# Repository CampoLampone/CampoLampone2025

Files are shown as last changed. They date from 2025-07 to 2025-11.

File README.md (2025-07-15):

# CampoLampone2025
This is repo for Firmware, PCBs, Images, schemes and stuff

## Setup

1) Clone with all the submodules
```
	git clone <repository-name-ssh-or-https> --recursive
```

2) Add TinyUSB to SDK
```
	cd pico-sdk && git submodule update --init
```

3) Create build dir and build da project!
```
	mkdir build && cd build
	cmake ..
	make -j<number of jobs>
```

## TODO

- [ ] Check when to move from pico-sdk develop branch to main branch

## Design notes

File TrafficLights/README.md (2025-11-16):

# Traffic lights
The traffic lights of Campo Lampone's city can be controlled by any Wifi capable MCU, in the case of Campo Lampone 2025 it was ESP32-S3 with MicroPython.
All of them depend on a central server with the schedule in it, they also sync to NTP.

Every controller has it's own `CONTROLLER_NAME` under which it tries to download it's config on start.

## Server
The shedule is kept in a JSON file by the [main server](server/main.py). The server is written in Python using FastAPI.
It has a relatively friendly frontend made in React with Vite coded with the help of an LLM. Its code is [here](campo/).

Both of them can be conveniently started at the same time in Docker using:
```bash
docker compose up -d
```
That opens the backend on port `8000` and an Nginx server serving a statically built version of the frontend on the port `8080`.

## Controllers
After installing MicroPython on your Wifi capable MCU of choice, you can install `main.py` on the device using MicroPython's `mpremote` utility.
Before copying the code on the device, you should replace these placeholders in the code:
- `WIFI_SSID`
- `WIFI_PASSWORD`
- `BACKEND_URL`
- `CONTROLLER_NAME`

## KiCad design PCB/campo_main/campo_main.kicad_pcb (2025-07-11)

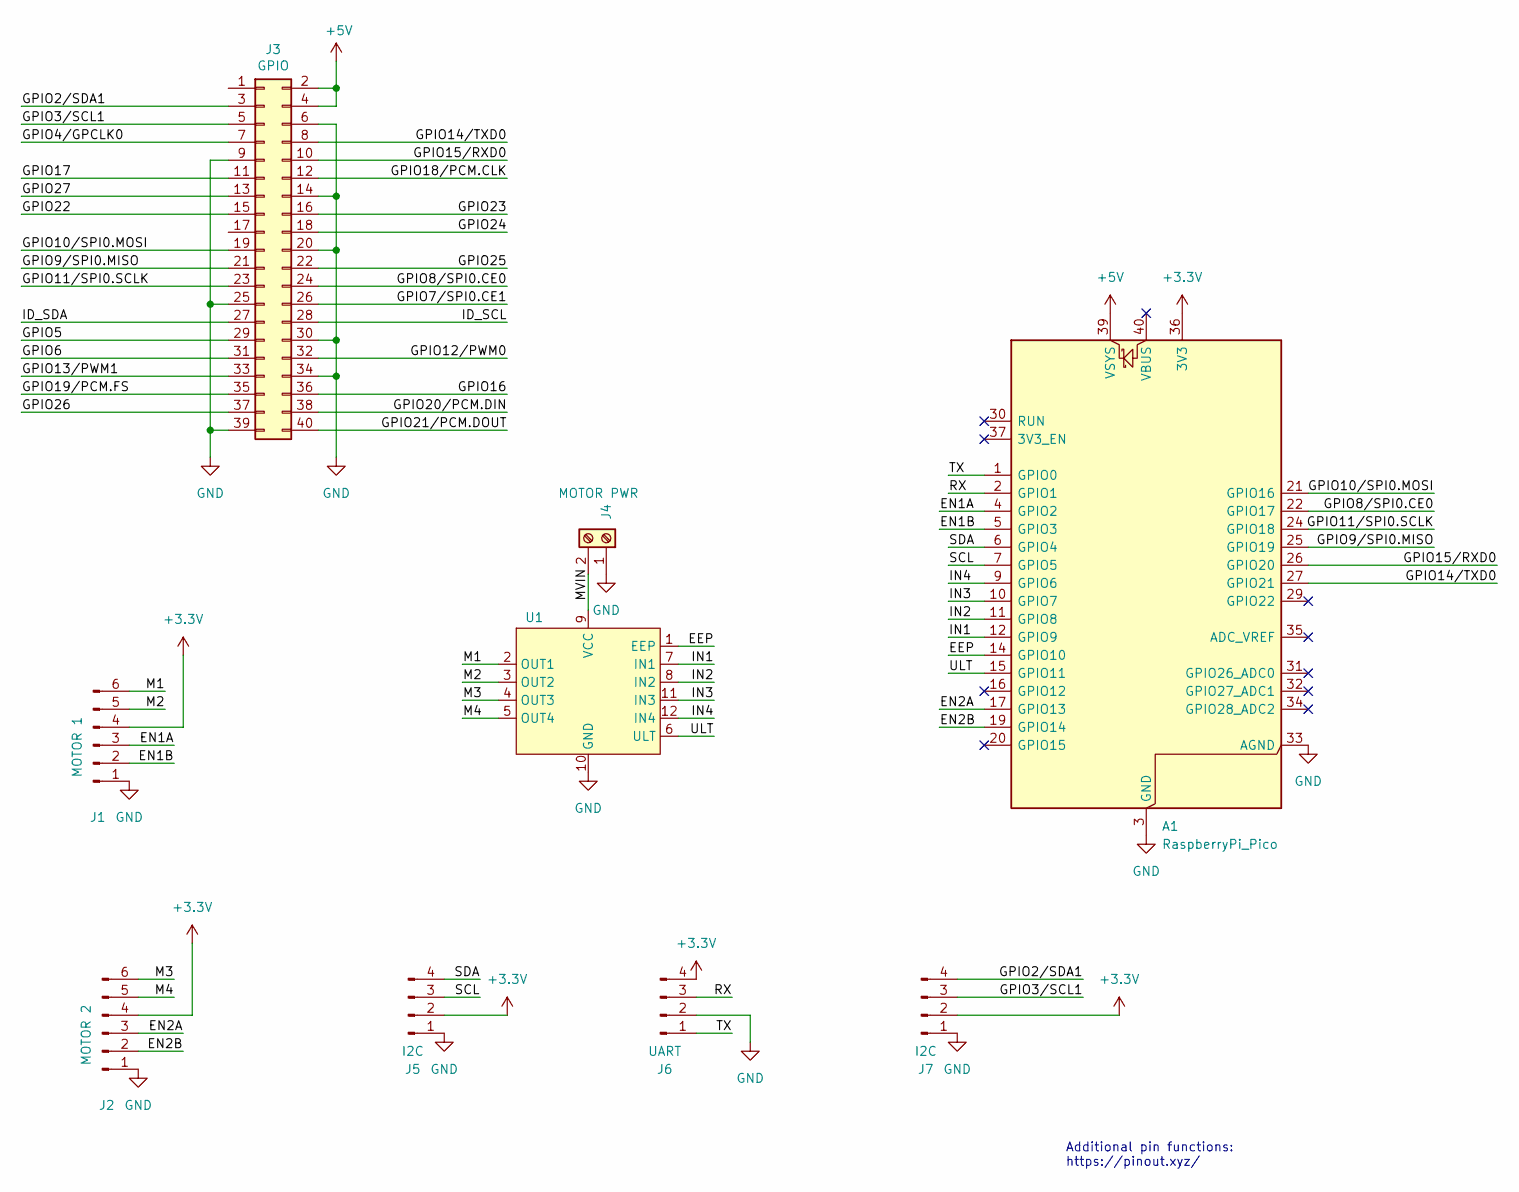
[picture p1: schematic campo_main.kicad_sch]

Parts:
A1: RaspberryPi_Pico; RaspberryPi_Pico_Common_Unspecified
J1: MOTOR 1; PinHeader_1x06_P2.54mm_Vertical
J2: MOTOR 2; PinHeader_1x06_P2.54mm_Vertical
J3: GPIO; PinSocket_2x20_P2.54mm_Vertical
J4: MOTOR PWR; TerminalBlock_4Ucon_1x02_P3.50mm_Horizontal
J5, J7: I2C; PinHeader_1x04_P2.54mm_Vertical
J6: UART; PinHeader_1x04_P2.54mm_Vertical
U1: DRV8833

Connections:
+3.3V: A1.36 (3V3), J1.4, J2.4, J5.2, J6.4, J7.2
+5V: A1.39 (VSYS), J3.2, J3.4
/EEP: A1.14 (GPIO10), U1.1 (EEP)
/EN1A: A1.4 (GPIO2), J1.3
/EN1B: A1.5 (GPIO3), J1.2
/EN2A: A1.17 (GPIO13), J2.3
/EN2B: A1.19 (GPIO14), J2.2
/GPIO2/SDA1: J3.3, J7.4
/GPIO3/SCL1: J3.5, J7.3
/GPIO4/GPCLK0: J3.7
/GPIO5: J3.29
/GPIO6: J3.31
/GPIO7/SPI0.CE1: J3.26
/GPIO8/SPI0.CE0: A1.22 (GPIO17), J3.24
/GPIO9/SPI0.MISO: A1.25 (GPIO19), J3.21
/GPIO10/SPI0.MOSI: A1.21 (GPIO16), J3.19
/GPIO11/SPI0.SCLK: A1.24 (GPIO18), J3.23
/GPIO12/PWM0: J3.32
/GPIO13/PWM1: J3.33
/GPIO14/TXD0: A1.27 (GPIO21), J3.8
/GPIO15/RXD0: A1.26 (GPIO20), J3.10
/GPIO16: J3.36
/GPIO17: J3.11
/GPIO18/PCM.CLK: J3.12
/GPIO19/PCM.FS: J3.35
/GPIO20/PCM.DIN: J3.38
/GPIO21/PCM.DOUT: J3.40
/GPIO22: J3.15
/GPIO23: J3.16
/GPIO24: J3.18
/GPIO25: J3.22
/GPIO26: J3.37
/GPIO27: J3.13
/ID_SCL: J3.28
/ID_SDA: J3.27
/IN1: A1.12 (GPIO9), U1.7 (IN1)
/IN2: A1.11 (GPIO8), U1.8 (IN2)
/IN3: A1.10 (GPIO7), U1.11 (IN3)
/IN4: A1.9 (GPIO6), U1.12 (IN4)
/M1: J1.6, U1.2 (OUT1)
/M2: J1.5, U1.3 (OUT2)
/M3: J2.6, U1.4 (OUT3)
/M4: J2.5, U1.5 (OUT4)
/MVIN: J4.2, U1.9 (VCC)
/RX: A1.2 (GPIO1), J6.3
/SCL: A1.7 (GPIO5), J5.3
/SDA: A1.6 (GPIO4), J5.4
/TX: A1.1 (GPIO0), J6.1
/ULT: A1.15 (GPIO11), U1.6 (ULT)
GND: A1.3 (GND), A1.8 (GND), A1.13 (GND), A1.18 (GND), A1.23 (GND), A1.28 (GND), A1.33 (AGND), A1.38 (GND), J1.1, J2.1, J3.6, J3.9, J3.14, J3.20, J3.25, J3.30, J3.34, J3.39, J4.1, J5.1, J6.2, J7.1, U1.10 (GND)

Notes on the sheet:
Additional pin functions: https://pinout.xyz/

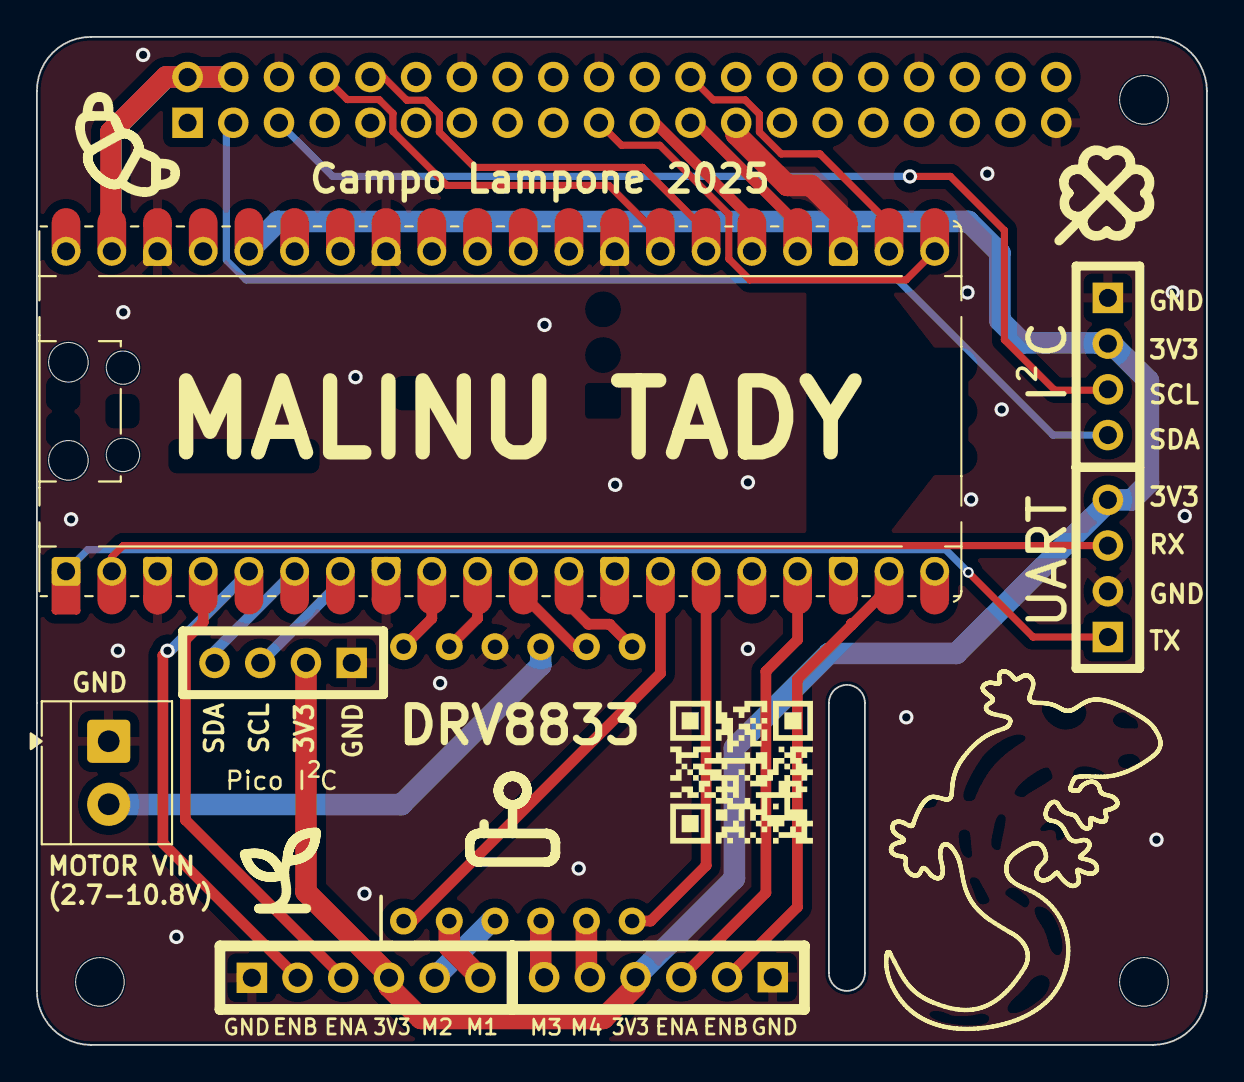
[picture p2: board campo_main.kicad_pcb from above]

Board: 2 copper layers, 65.0 x 56.0 mm, 12 parts (1 on the bottom side), 30 nets.

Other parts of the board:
MH2, MH3, MH4: MountingHole_2.7mm_M2.5

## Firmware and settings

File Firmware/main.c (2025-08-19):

#include "speed_controller.h"
#include <stdint.h>
#include <stdio.h>
#include "pico/stdio_usb.h"
#include <pico/time.h>
#include <string.h>
#include "hardware/i2c.h"
#include "motor.h"
#include "encoder.h"
#include "display.h"
#include "config.h"
#include "spi.h"
#include "spi_cmds.h"

#if TEST_MODE > 0
#include "tests.h"
#endif

enum command {
    COMMAND_SPEED,
    COMMAND_POSITION,
    COMMAND_BRAKE,
    COMMAND_STOP,
    COMMAND_COAST
};

int16_t speed_target[MOTOR_COUNT] = {0, 0};
int8_t position_target[MOTOR_COUNT] = {0, 0};
uint8_t current_cmd = COMMAND_COAST;
substep_state_t encoders_states[ENCODER_COUNT];
display_data_t display_struct;

void spi_callback(uint8_t *data){
    switch (data[0]) {
        case SPI_CMD_SET_SPEED_BASE:
            current_cmd = COMMAND_SPEED;
            speed_target[0] = (data[1] << 8) | data[2];
            break;
        case SPI_CMD_SET_SPEED_BASE + SPI_CMD_NEXT_MOTOR:
            current_cmd = COMMAND_SPEED;
            speed_target[1] = (data[1] << 8) | data[2];
            break;
        case SPI_CMD_SET_POSITION_BASE:
            current_cmd = COMMAND_POSITION;
            position_target[0] = data[1];
            speed_target[0] = (data[2] << 8) | data[3];
            break;
        case SPI_CMD_SET_POSITION_BASE + SPI_CMD_NEXT_MOTOR:
            current_cmd = COMMAND_POSITION;
            position_target[1] = data[1];
            speed_target[1] = (data[2] << 8) | data[3];
            break;
        case SPI_CMD_COAST:
            current_cmd = COMMAND_COAST;
            break;
        case SPI_CMD_BRAKE:
            current_cmd = COMMAND_BRAKE;
            break;
        case SPI_CMD_REL_ESTOP:
            reset_emergency_stop();
            clear_pid_cache();
            break;
        case SPI_CMD_SET_HOSTNAME:
            strcpy(display_struct.ip, (char*)&data[1]);
            break;
    }
}


int main() {
    stdio_usb_init();
    sleep_ms(2000);
    printf("Program Started\n");
#if TEST_MODE == 0
    motor_init();
    encoders_init();
    spi_init(spi_callback);
    speed_controller_init(PID_KP, PID_KI, PID_KD);
    reset_emergency_stop();
    i2c_init(i2c_default, 400 * 1000);
    ssd1306_gpio_init(PICO_DEFAULT_I2C_SDA_PIN, PICO_DEFAULT_I2C_SCL_PIN);

    ssd1306_t disp;
    disp.external_vcc=false;

    // Check if the device is present

    int ret = i2c_read_timeout_us(i2c_default, 0x3C, NULL, 1, false, 10000);

    if (ret >= 0) {
        printf("I2C device found at address 0x%02X\n", 0x3C);
        ssd1306_init(&disp, 128, 64, true, 0x3C, i2c_default);
        ssd1306_clear(&disp);
    } else {
        printf("No I2C device found at address 0x%02X. Is the display connected correctly?\n", 0x3C);
    }

    absolute_time_t last_time = get_absolute_time();
    int wrum_time = last_time;
    while (true) {
        absolute_time_t current_time = get_absolute_time();
        int64_t delta_us = absolute_time_diff_us(last_time, current_time);
        last_time = current_time;

        compute_encoders_rpm(delta_us / 1000.0);
        switch (current_cmd) {
            case (COMMAND_SPEED):
                control_speed(speed_target, delta_us / 1000.0);
                break;
            case (COMMAND_POSITION):
                // TODO: Implement position control
                // control_position(position_target, speed_target, delta_us / 1000.0);
                break;
            case (COMMAND_COAST):
                for (int motor = 0; motor < MOTOR_COUNT; motor++) {
                    motor_coast(motor);
                }
                break;
            case (COMMAND_BRAKE):
                for (int motor = 0; motor < MOTOR_COUNT; motor++) {
                    motor_brake(motor);
                }
                break;
        }

        if (ret >= 0) {
            snprintf(display_struct.msg, DISP_BUF(MSG_SCALE), get_emergency_stop() ? "ESTOP" : "     ");
            snprintf(display_struct.stuff, DISP_BUF(STUFF_SCALE), "%4.0f  %4.0f", get_rpm(MOTOR_LEFT), get_rpm(MOTOR_RIGHT));
            ssd1306_draw_struct(&disp, &display_struct);
            ssd1306_show(&disp);
        }

        sleep_ms(10); // loop delay for PID
    }
#elif TEST_MODE > 0
    do_tests();
#endif

}

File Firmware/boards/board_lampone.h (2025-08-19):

/*
 * Copyright (c) 2020 Raspberry Pi (Trading) Ltd.
 *
 * Edited to suit LampOne's board - Plajta 2025 - Salivon Andrii
 *
 * SPDX-License-Identifier: BSD-3-Clause
 */

// -----------------------------------------------------
// NOTE: THIS HEADER IS ALSO INCLUDED BY ASSEMBLER SO
//       SHOULD ONLY CONSIST OF PREPROCESSOR DIRECTIVES
// -----------------------------------------------------

#ifndef _BOARDS_LAMPONE_H
#define _BOARDS_LAMPONE_H

// For board detection
#define LAMPONE

//---------------------------//
//   BOARD PIN DEFINITIONS   //
//---------------------------//
#include "boards/pico.h" // IWYU pragma: keep

// --- MOTOR PINS ---
#define BOARD_MOTOR_EEP 10
#define BOARD_MOTOR_PIN_1 9 // LEFT
#define BOARD_MOTOR_PIN_2 8
#define BOARD_MOTOR_PIN_3 7 // RIGHT
#define BOARD_MOTOR_PIN_4 6

// --- ENCODER PINS ---
#define BOARD_ENCODER1_PIN_A 2 // LEFT
#define BOARD_ENCODER1_PIN_B 3
#define BOARD_ENCODER2_PIN_A 13 // RIGHT
#define BOARD_ENCODER2_PIN_B 14

#endif //_BOARDS_LAMPONE_H

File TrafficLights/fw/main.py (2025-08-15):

# "defines" - always check before deploy
WIFI_SSID = "<YOUR SSID>"
WIFI_PASSWORD = "<YOUR PASSWD>"

BACKEND_URL = "http://192.168.1.156:8000"

CONTROLLER_NAME = "controller1"
NUM_LIGHTS = 2

# setup network
import machine
import network

wlan = network.WLAN()
wlan.active(True)
if not wlan.isconnected():
    print('connecting to network...')
    wlan.connect(WIFI_SSID, WIFI_PASSWORD)
    while not wlan.isconnected():
        machine.idle()
print('network config:', wlan.ipconfig('addr4'))

# sync time
from machine import RTC
import ntptime

rtc = RTC()
ntptime.settime()
print("Datetime: " + str(rtc.datetime()))

# get JSON
import requests
import json

url = BACKEND_URL + "/controllers/" + CONTROLLER_NAME

data = None

try:
    r = requests.get(url)
    if r.status_code == 200:
        data = json.loads(r.text)
        print("Received JSON:", data)
    else:
        print("HTTP Error:", r.status_code)
    r.close()  # important to free memory
except Exception as e:
    print("Request failed:", e)

# setup traffic lights

from machine import Pin, Timer
import time

class Light:
    def __init__(self, red, yellow, green):
        self.red = red
        self.yellow = yellow
        self.green = green
        self.last_outage = False

    def tick_outage(self):
        if not self.last_outage:
            self.last_outage = True
            self.red.off()
            self.yellow.on()
            self.green.off()
        else:
            self.yellow.toggle()

    def set_phase(self, phase):
        self.last_outage = False
        phase_states = {
            "red":       (1, 0, 0),
            "redyellow": (1, 1, 0),
            "yellow":    (0, 1, 0),
            "green":     (0, 0, 1),
            "off":       (0, 0, 0),
        }

        # Get the current state, default to all off if unknown
        r_state, y_state, g_state = phase_states.get(phase, (0, 0, 0))

        self.red.on() if r_state else self.red.off()
        self.yellow.on() if y_state else self.yellow.off()
        self.green.on() if g_state else self.green.off()

lights = [Light(Pin(0, Pin.OUT), Pin(2, Pin.OUT), Pin(3, Pin.OUT))]

schedule_lengths = []

if type(data['lights']) is list:
    for light in data['lights']:
        phases = light['phases']
        schedule_lengths.append(0)
        for phase in phases:
            schedule_lengths[-1] += phase['duration']
else:
    raise ValueError("Invalid data format")

print(schedule_lengths)

# setup timer and start ticking

def tick(timer):
    micropython_epoch_offset = 946684800
    epoch = time.time() + micropython_epoch_offset
    for i in range(NUM_LIGHTS):
        if i >= len(lights):
            break

        if data['outages']['enabled'] and (epoch % data['outages']['period']) < data['outages']['duration']:
            print("Outage")
            lights[i].tick_outage()
            continue

        tick = epoch % schedule_lengths[i]
        for phase in data['lights'][i]['phases']:
            if tick < phase['duration']:
                print(f"Light {i} phase: {phase['color']}")
                lights[i].set_phase(phase['color'])
                break
            tick -= phase['duration']
    # print("Tick at", rtc.datetime())

us = rtc.datetime()[7]
delay = 1000000 - (us % 1000000)  # ms until next full second
time.sleep_us(delay - 1200) # 1200 cuz it seemed like the time it will take

# Start aligned hardware timer
tim = Timer(0)
tim.init(period=1000, mode=Timer.PERIODIC, callback=tick)

while True:
    time.sleep(1)

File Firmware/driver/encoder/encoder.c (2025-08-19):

/**
 * Copyright (c) 2023 Raspberry Pi (Trading) Ltd.
 *
 * SPDX-License-Identifier: BSD-3-Clause
 */

#include <stdio.h>
#include <string.h>
#include "hardware/pio.h"
#include <pico/divider.h>

#include "encoder.h"
#include "quadrature_encoder_substep.pio.h"

//
// ---- quadrature encoder interface with sub-step accuracy
//
// At low speeds, or high sample rates, a quadrature encoder can produce a small
// number of steps per sample, which makes any speed estimate made from those
// counts to be very noisy.
//
// This code uses a PIO program to count steps like the standard quadrature
// encoder example, but also mark the timestamp of the last step transition,
// which then allows the sampling code to measure the actual speed by computing
// the time passed between transitions and the "distance" traveled. See
// README.md for more details

// the quadrature encoder code starts here

// internal helper functions (not to be used by user code)

static void read_pio_data(substep_state_t *state, uint *step, uint *step_us, uint *transition_us, int *forward)
{
    int cycles;

    // get the raw data from the PIO state machine
    quadrature_encoder_substep_get_counts(state->pio, state->sm, step, &cycles, step_us);

    // when the PIO program detects a transition, it sets cycles to either zero
    // (when step is incrementing) or 2^31 (when step is decrementing) and keeps
    // decrementing it on each 13 clock loop. We can use this information to get
    // the time and direction of the last transition
    if (cycles < 0) {
        cycles = -cycles;
        *forward = 1;
    } else {
        cycles = 0x80000000 - cycles;
        *forward = 0;
    }
    *transition_us = *step_us - ((cycles * 13) / state->clocks_per_us);
}

// get the sub-step position of the start of a step
static uint get_step_start_transition_pos(substep_state_t *state, uint step)
{
    return ((step << 6) & 0xFFFFFF00) | state->calibration_data[step & 3];
}

// compute speed in "sub-steps per 2^20 us" from a delta substep position and
// delta time in microseconds. This unit is cheaper to compute and use, so we
// only convert to "sub-steps per second" once per update, at most
static int substep_calc_speed(int delta_substep, int delta_us)
{
    return ((int64_t) delta_substep << 20) / delta_us;
}



// main functions to be used by user code

// initialize the substep state structure and start PIO code
void substep_init_state(PIO pio, int sm, int pin_a, substep_state_t *state)
{
    int forward;

    // set all fields to zero by default
    memset(state, 0, sizeof(substep_state_t));

    // initialize the PIO program (and save the PIO reference)
    state->pio = pio;
    state->sm = sm;
    quadrature_encoder_substep_program_init(pio, sm, pin_a);

    // start with equal phase size calibration
    state->calibration_data[0] = 0;
    state->calibration_data[1] = 64;
    state->calibration_data[2] = 128;
    state->calibration_data[3] = 192;

    state->idle_stop_samples = 3;

    // start "stopped" so that we don't use stale data to compute speeds
    state->stopped = 1;

    // cache the PIO cycles per us
    state->clocks_per_us = (clock_get_hz(clk_sys) + 500000) / 1000000;

    // initialize the "previous state"
    read_pio_data(state, &state->raw_step, &state->prev_step_us, &state->prev_trans_us, &forward);

    state->position = get_step_start_transition_pos(state, state->raw_step) + 32;
}


// read the PIO data and update the speed / position estimate
void substep_update(substep_state_t *state)
{
    uint step, step_us, transition_us, transition_pos, low, high;
    int forward, speed_high, speed_low;

    // read the current encoder state from the PIO
    read_pio_data(state, &step, &step_us, &transition_us, &forward);

    // from the current step we can get the low and high boundaries in substeps
    // of the current position
    low = get_step_start_transition_pos(state, step);
    high = get_step_start_transition_pos(state, step + 1);

    // if we were not stopped, but the last transition was more than
    // "idle_stop_samples" ago, we are stopped now
    if (step == state->raw_step)
        state->idle_stop_sample_count++;
    else
        state->idle_stop_sample_count = 0;

    if (!state->stopped && state->idle_stop_sample_count >= state->idle_stop_samples) {
        state->speed = 0;
        state->speed_2_20 = 0;
        state->stopped = 1;
    }

    // when we are at a different step now, there is certainly a transition
    if (state->raw_step != step) {
        // the transition position depends on the direction of the move
        transition_pos = forward ? low : high;

        // if we are not stopped, that means there is valid previous transition
        // we can use to estimate the current speed
        if (!state->stopped)
            state->speed_2_20 = substep_calc_speed(transition_pos - state->prev_trans_pos, transition_us - state->prev_trans_us);

        // if we have a transition, we are not stopped now
        state->stopped = 0;
        // save the timestamp and position of this transition to use later to
        // estimate speed
        state->prev_trans_pos = transition_pos;
        state->prev_trans_us = transition_us;
    }

    // if we are stopped, speed is zero and the position estimate remains
    // constant. If we are not stopped, we have to update the position and speed
    if (!state->stopped) {
        // although the current step doesn't give us a precise position, it does
        // give boundaries to the position, which together with the last
        // transition gives us boundaries for the speed value. This can be very
        // useful especially in two situations:
        // - we have been stopped for a while and start moving quickly: although
        //   we only have one transition initially, the number of steps we moved
        //   can already give a non-zero speed estimate
        // - we were moving but then stop: without any extra logic we would just
        //   keep the last speed for a while, but we know from the step
        //   boundaries that the speed must be decreasing
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

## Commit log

2025-07-08 Some PCB work around
    [campo_main.kicad_pcb, campo_main.kicad_sch]
2025-07-08 Update schematic
    [campo_main.kicad_pcb, campo_main.kicad_sch]
2025-07-09 PCB update
    [campo_main.kicad_pcb, campo_main.kicad_sch]
2025-07-09 Added assets for PCB
2025-07-09 Upgrade silkscreen
    [campo_main.kicad_pcb, campo_main.kicad_sch]
2025-07-09 Fix broken traces
    [campo_main.kicad_pcb]
2025-07-09 Fix for PCB
    [campo_main.kicad_pcb, campo_main.kicad_sch]
2025-07-10 Some PCB Changes
    [campo_main.kicad_pcb, campo_main.kicad_sch]
2025-07-10 Added some assets needed to PCB
2025-07-11 PCB final
    [campo_main.kicad_pcb]
2025-07-12 Implemented motor pwm control, encoder read and pid speed control
2025-07-15 added some instructions + added pico-sdk/develop as submodule
2025-07-31 Removed pico-sdk submodule
2025-07-31 Playing with PID
2025-08-07 Hard-fixed motors and encoders
2025-08-07 Improved motors driver
2025-08-07 [MERGE] Added substep encoder, it sexy, but I don't understand yet...
2025-08-09 Fixed recomputation to RPM
    [encoder.c, main.c]
2025-08-10 SPI works!
2025-08-11 [Merge] Some directional fixes
    [main.c, tests.c]
2025-08-11 Some improvements, added brake and coast cmd
2025-08-11 Fixed encoders in tests
    [speed_controller.c, speed_controller.h, tests.c]
2025-08-15 Add traffic light infrastructure
    A React frontend for configuring the traffic lights
    with a FastAPI backend all packed in Docker
    Docker compose for painless deploying
    Micropython code for the ESPs (you could probably use Pico Ws) that
    control the actual LEDs
2025-08-15 Clearing pid cache when sets new target value
2025-08-17 Added emergence stop, when motors stall
    [main.c, speed_controller.c, speed_controller.h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]
2025-08-18 Small typo 😅
2025-08-18 Added estop reset to SPI commands
    [main.c]
2025-08-18 WIP: Added SSD1306 code (not implemented correctly yet)
    [display.c]
2025-08-19 Some fixes and stuf 👲
    [main.c, speed_controller.h, tests.c]
2025-08-19 Repaired speed printing on display
2025-08-19 Added Setting hostname via SPI 🧚
2025-08-21 Small Pid shit 🪥
2025-08-22 Added low pass filter
